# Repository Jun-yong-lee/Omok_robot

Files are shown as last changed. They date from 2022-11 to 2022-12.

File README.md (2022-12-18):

# Omok_robot
Omok robot(Senier Project)

omok_robot_play
## Link https://youtu.be/_ZdAu9by-7Q

## Matlab Simulation
<p align="center">

</p>

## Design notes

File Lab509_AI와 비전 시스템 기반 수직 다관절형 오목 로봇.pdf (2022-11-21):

# AI와 비전 시스템 기반 수직 다관절형 오목 로봇

## 이준용, 이성용, 박정섭, 김선혁(지도교수 김우용)

## 호서대학교 로봇공학과

## Department of Robotics, Hoseo University

- 사용자와 1대1 오목대국이 가능한 오목 로봇 제작
- 오목게임을 진행할 수 있는 대결 플랫폼 제작
- 오목판 격자무늬 포인트에 정확하게 돌을 착수 할 수 있는 제어 시스템 설계
- 오목판 모든 좌표에 돌을 둘 수 있는 5축 로봇팔 설계
✓ | DH 파라미터와 매트랩 시뮬레이션을 통한 로봇팔 길이 선정
✓ | 유성기어를 활용한 정밀성 및 토크 향상
- 다이나믹셀을 활용한 5축 로봇팔 제어
✓ | PID 제어기 설계를 통한 포지션 제어
✓ | 5축 로봇팔 제어를 통한 정확한 좌표로의 이동
- CV(Computer Vision)를 활용한 오목판 위의 돌의 좌표 추출
✓ | Sobel연산을 이용한 격자무늬 포인트 추출
✓ | Templete Matching을 이용한 오목돌 감지
- CNN(Convolution Neural)을 활용한 오목 AI 모델 생성

✓ FreeStyle Rule을 적용한 오목 AI 모델 생성

- Pygame을 활용한 UI(User Interface)제작
✓ 승패 판정 및 마우스 클릭 이벤트가 가능한 UI 제공

### 연구목표

서론

결론

<goboard detect> | <stone detect>

<detect result>

1. Soble연산을 이용한 오목판의 격자무늬 포인트 좌표 탐지
2. Templete Matching을 이용한 오목돌 좌표 탐지
3. 포인트와 오목돌 좌표를 비교 연산하여 실제 돌의 착수 좌표 검출
1. Gomocup Freestyle data 전처리를 통한 데이터 확보
2. CNN(Convolution Neural Network)을 활용한 오목 AI 모델 학습 진행
3. 실제 오목이 진행되는 배열을 입력으로 한 AI 모델 성능 검증

<CV detect result>

Hardware

1. 오목돌의 Pick & Place를 위해 5-axis Manipulator를 제작
2. 전체 내부의 구성은 모터와 모터 연결 축이 Manipulator 각 링크에 다이렉트로 연결
3. Joint 2번만 모터 토크 부족으로 Sun gear 기준 6:1 비율의 유성기어를 장착하여 토크 향상
4. Board Box, Dispenser와 함께 오목로봇 전체구성
<전체 Asembly> | <실제 외형>

Kinematics

1. Matlab을 이용하여 경기장에서 구동 가능한 수직 다관절형 로봇팔의 DH 파라미터를 선정
2. 그림1과 2는 오목판 좌표(4,4)의 역기구학 분석을 진행한 뒤, 그 결과를 순기구학을 이용하여 오목판, 로봇팔의 형태를 plot에 시각화
3. 그림 3은 제작된 로봇팔로 오목판의 모든 좌표에 오목돌 착수 가능여부를 시각화
<그림 1> | <그림 2> | <그림 3>

Firmware

1. 그림 4는 오목돌을 착수할 5축 로봇팔과 경기장의 자동화를 위한 오목돌 디스펜서의 전체적인 시스템 개략도
2. 그림 5는 오목 로봇을 구성하는데 사용된 DYNAMIXEL의 정보
3. 로봇팔의 돌 착수에는 다른 좌표에 두어진 오목돌을 피해 지나갈 수 있도록 End-Effector가 지정된 경로를 따라 진행하도록 경로설계를 진행
<그림 4> | <그림 5>

Computer Vision

CNN based AI

Pygame based UI

Omok Robot System

<AI model Layer Configuration>

<Accuracy Trend>

<Loss Trend>

- 오목로봇의 각각의 요소인 Hardware, Firmware, CV, AI, UI를 완성 & 연동
- 로봇과 사용자가 대결이 가능한 오목 로봇 플랫폼 완성
- AI가 융합된 교육 로봇 플랫폼 개발 가능성 제시
- 현재 개발된 모델과 매우 흡사한 바둑과 체스 등 다양한 시스템에 적용 가능
1. 사용자가 착수한 돌과 AI가 착수한 돌을 UI상에 출력
2. 턴이 끝나면 마다 오목 룰 알고리즘으로 게임 종료 판단
3. 사용자로부터 이름을 입력 받아 ranking system 구현

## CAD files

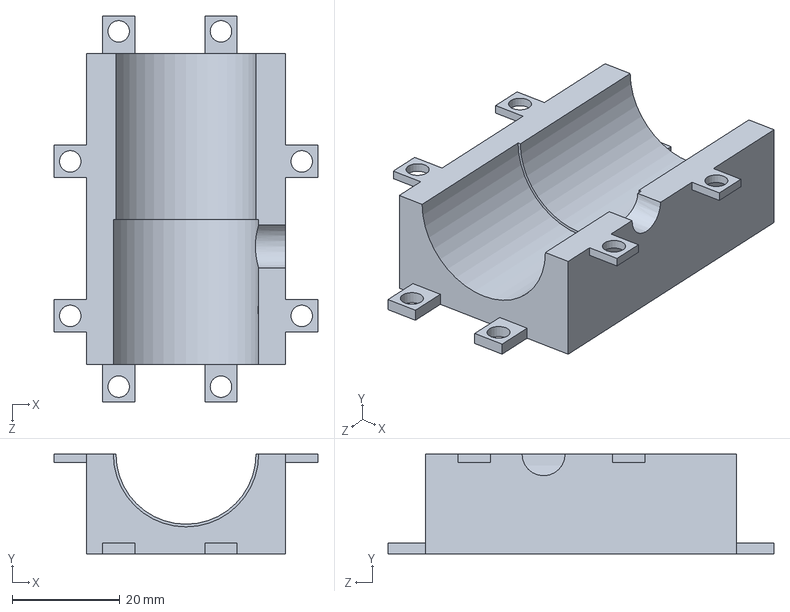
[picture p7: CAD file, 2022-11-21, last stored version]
design_board_box/Vacuum Pump case.SLDPRT
49.0 x 18.5 x 71.7 mm

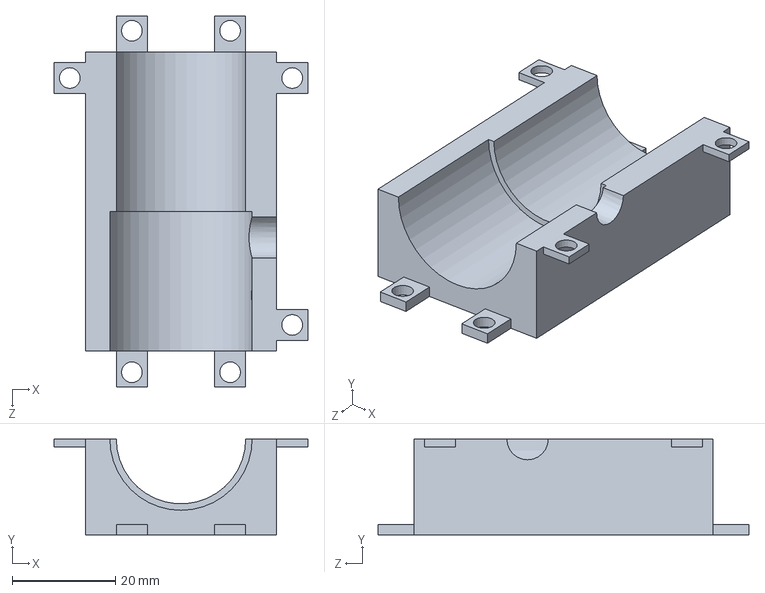
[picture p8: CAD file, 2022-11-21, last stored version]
design_board_box/치수 늘린 모터 케이스/치수_Vacuum Pump case 하.SLDPRT
49.0 x 18.5 x 71.7 mm

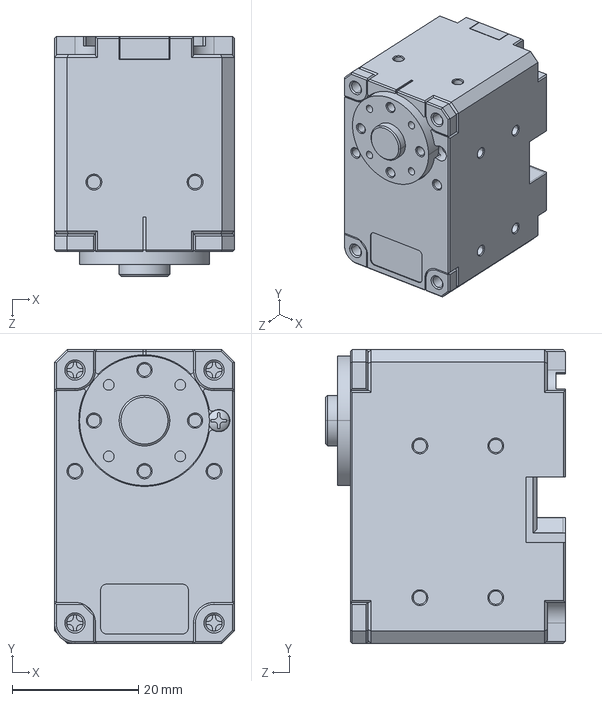
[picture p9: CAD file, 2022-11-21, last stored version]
design_dispenser/XL-430.SLDPRT
28.5 x 46.5 x 37.9 mm

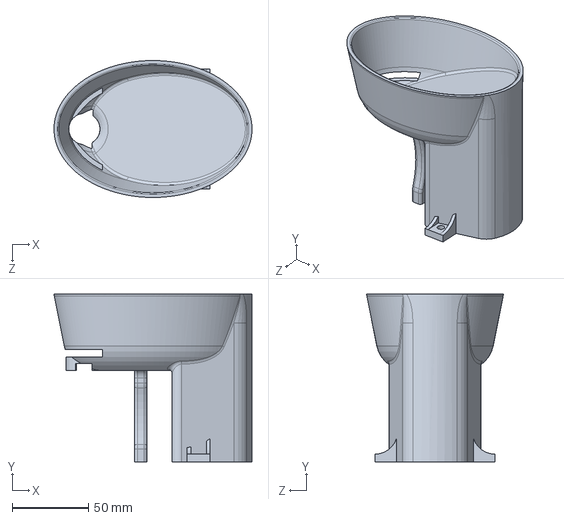
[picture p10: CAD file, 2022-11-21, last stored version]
design_dispenser/구조 변경/입X_stone case.SLDPRT
129.9 x 110.0 x 89.9 mm

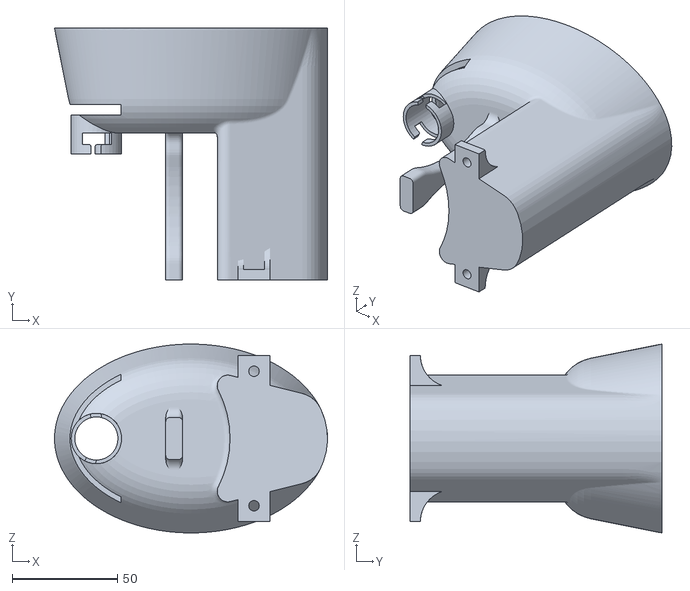
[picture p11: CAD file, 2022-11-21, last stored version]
design_dispenser/출력파일/stone case.STL
129.9 x 120.0 x 89.9

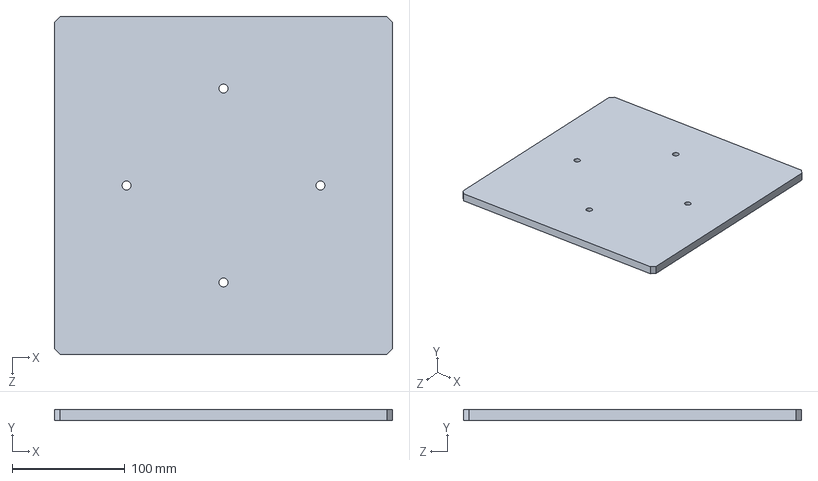
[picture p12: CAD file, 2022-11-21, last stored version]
design_place/Iron plate.SLDPRT
300.0 x 10.0 x 300.0 mm

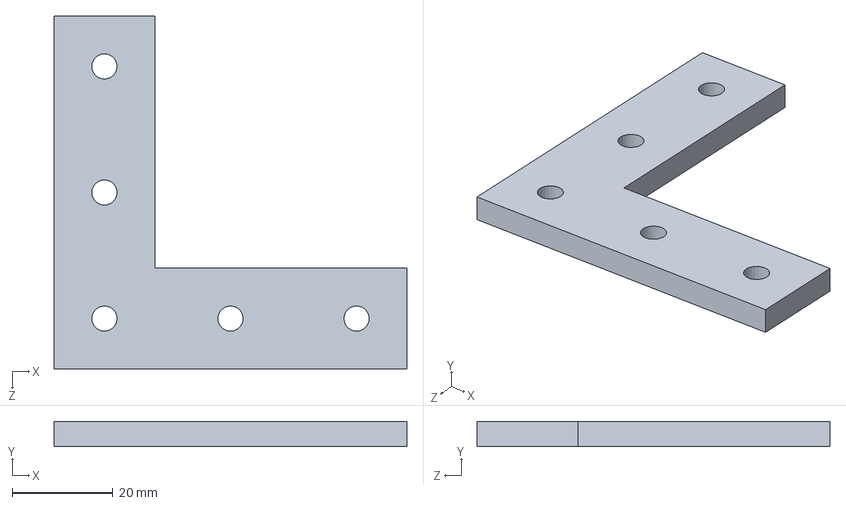
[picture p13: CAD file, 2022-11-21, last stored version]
ㄱ fixed flat.SLDPRT
70.0 x 5.00 x 70.0 mm

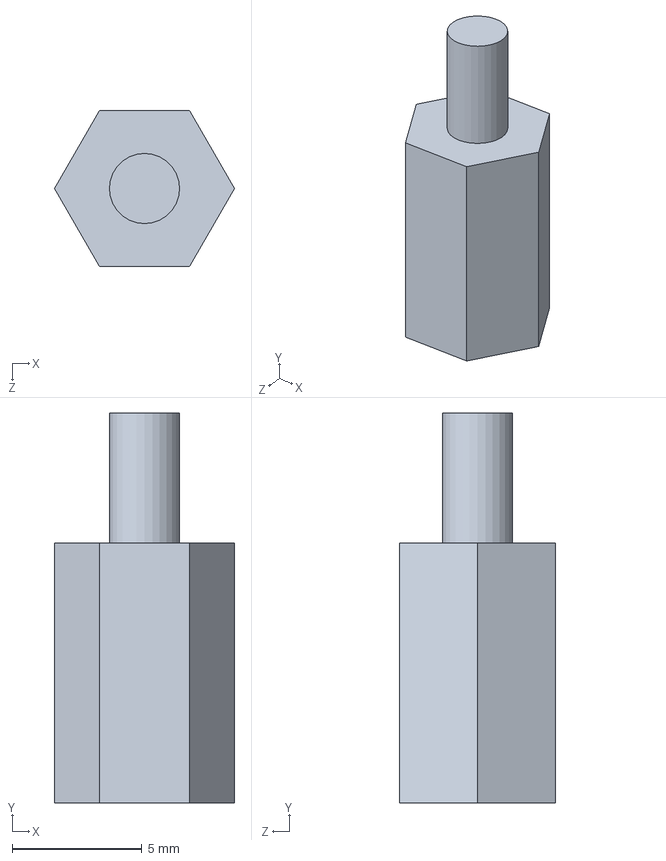
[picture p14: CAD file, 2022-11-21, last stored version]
design_board_box/board support_L10.SLDPRT
6.93 x 15.0 x 6.00 mm

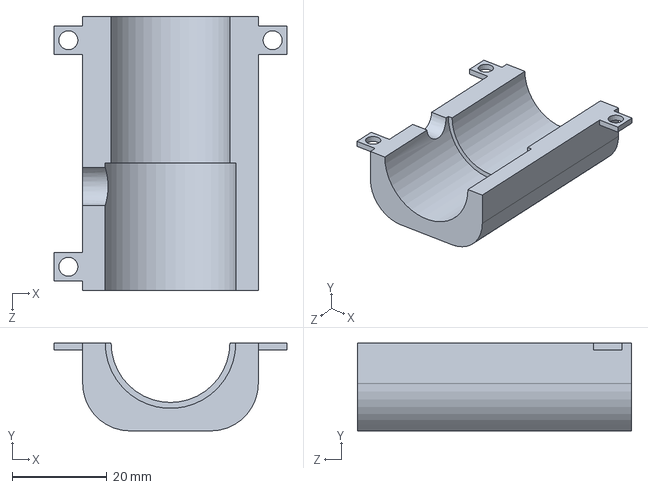
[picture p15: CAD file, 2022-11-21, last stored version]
design_board_box/치수 늘린 모터 케이스/치수_Vacuum Pump case 상.SLDPRT
49.0 x 18.5 x 57.7 mm

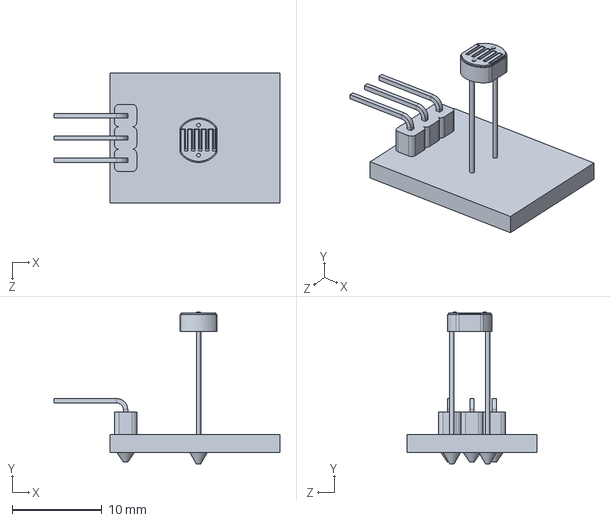
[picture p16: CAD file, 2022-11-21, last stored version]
design_dispenser/CDS module.SLDPRT
25.2 x 17.0 x 14.5 mm

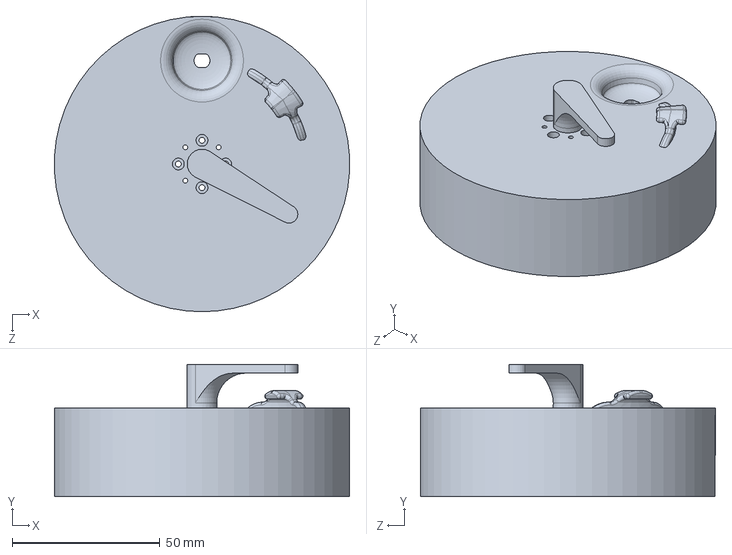
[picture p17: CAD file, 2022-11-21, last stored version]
design_dispenser/구조 변경/입X_Rotating plate.SLDPRT
99.9 x 44.8 x 100.0 mm

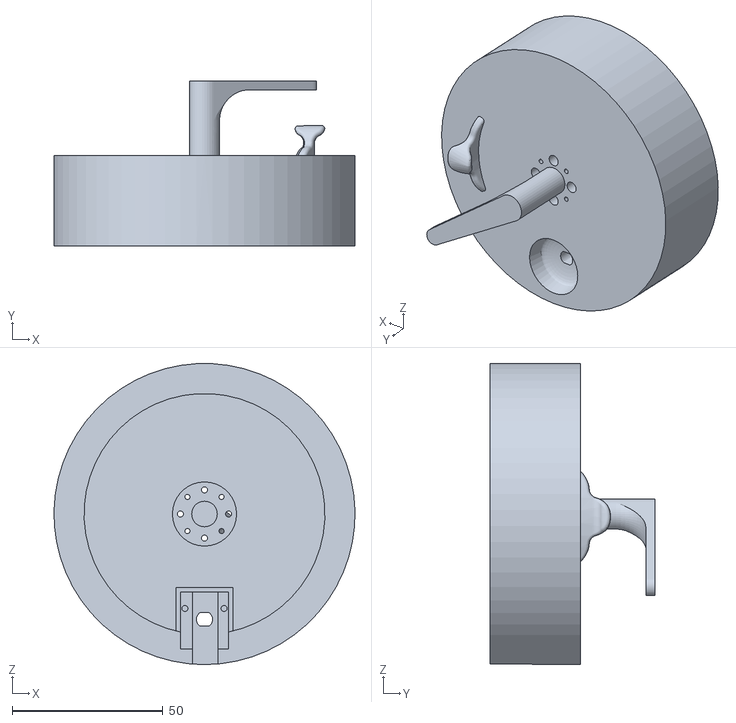
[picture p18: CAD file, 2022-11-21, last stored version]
design_dispenser/출력파일/Rotating plate.STL
100.0 x 54.8 x 100.0

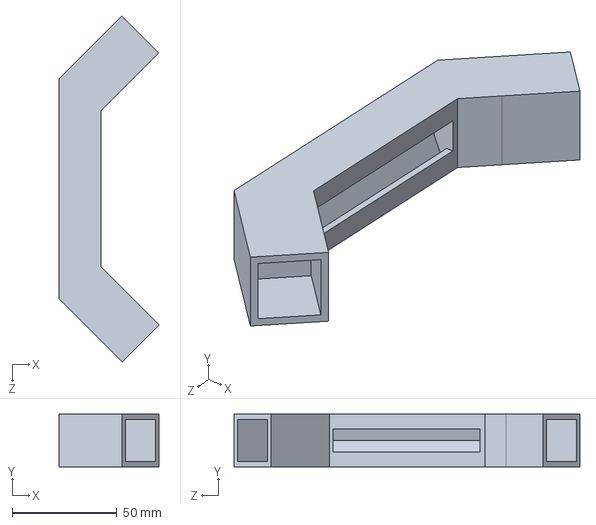
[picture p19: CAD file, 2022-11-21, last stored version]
design_place/Camera stand.SLDPRT
47.8 x 25.2 x 165.0 mm

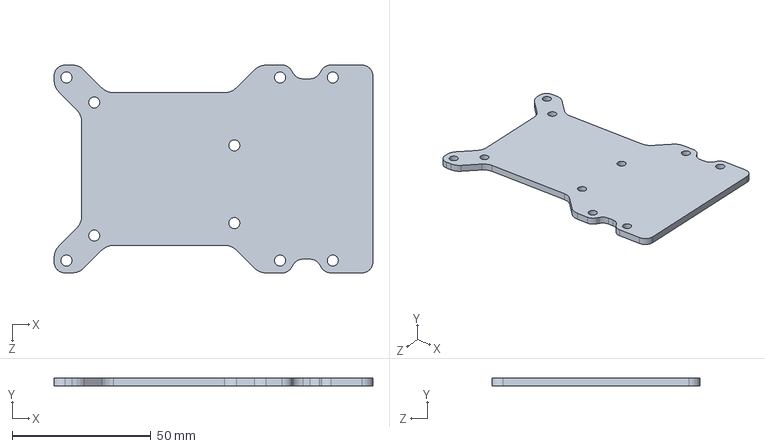
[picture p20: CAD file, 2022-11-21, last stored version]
design_board_box/2 plate.SLDPRT
115.0 x 3.00 x 75.0 mm

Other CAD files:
design_board_box/치수 늘린 모터 케이스/치수_solenoide fixed line.SLDPRT
design_dispenser/알.SLDPRT
design_place/Profile link.SLDPRT
design_board_box/solenoide fixed line.SLDPRT
design_board_box/1 plate.DWG
design_board_box/1 plate.SLDPRT
design_board_box/2 plate.DWG
design_board_box/Arduino uno.SLDPRT
design_board_box/SMD_R 1206 Body.stp.SLDPRT
design_board_box/SMD_R 1206 Connector.stp.SLDPRT
design_board_box/Sensor Board.SLDPRT
design_board_box/Vacuum Pump case 상.SLDPRT
design_board_box/Vacuum Pump case 상.STL
design_board_box/Vacuum Pump case.STL
design_board_box/Vacuum Pump.SLDPRT
design_board_box/board support_L20.SLDPRT
design_board_box/board support_L30.SLDPRT
design_board_box/board support_L5.SLDPRT
design_board_box/solenoide.SLDPRT
design_board_box/uno.step.SLDPRT
design_board_box/치수 늘린 모터 케이스/치수_Vacuum Pump case 상.STL
design_board_box/치수 늘린 모터 케이스/치수_Vacuum Pump case 하.STL
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

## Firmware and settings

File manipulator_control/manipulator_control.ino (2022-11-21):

/***********************************************************************************************************************
* Department of Robotics Hoseo University
* LAB509 Senier Project
* Project Name : Concave AI Manipulator System
* Project Period : 2022.01~2022.10
* < Lee Seong Yong > : Responsible for Making the Manipulator Controller
***********************************************************************************************************************/

/**********************************************************************************************************************
* Dynamixel : Extended Position Control Mode(OpenCR Board Use)
* 1) Joint1 : Dynamixel XH540-W270-T
* 2) Joint2 : Dynamixel XM540-W270-T
* 3) Joint3 : Dynamixel XM430-W350-T
* 4) End_Effector_A : Dynamixel 2XL430-W250-T(A)
* 5) End_Effector_B : Dynamixel 2XL430-W250-T(B)
***********************************************************************************************************************/
#include <Arduino.h>
#include <actuator.h>
#include <Dynamixel2Arduino.h>
#include <math.h>

HardwareTimer Timer(TIMER_CH1);

// Please modify it to suit your hardware.
#if defined(ARDUINO_AVR_UNO) || defined(ARDUINO_AVR_MEGA2560) // When using DynamixelShield
  #include <SoftwareSerial.h>
  SoftwareSerial soft_serial(7, 8); // DYNAMIXELShield UART RX/TX
  #define DXL_SERIAL   Serial
  #define DEBUG_SERIAL soft_serial
  const uint8_t DXL_DIR_PIN = 2; // DYNAMIXEL Shield DIR PIN
#elif defined(ARDUINO_SAM_DUE) // When using DynamixelShield
  #define DXL_SERIAL   Serial
  #define DEBUG_SERIAL SerialUSB
  const uint8_t DXL_DIR_PIN = 2; // DYNAMIXEL Shield DIR PIN
#elif defined(ARDUINO_SAM_ZERO) // When using DynamixelShield
  #define DXL_SERIAL   Serial1
  #define DEBUG_SERIAL SerialUSB
  const uint8_t DXL_DIR_PIN = 2; // DYNAMIXEL Shield DIR PIN
#elif defined(ARDUINO_OpenCM904) // When using official ROBOTIS board with DXL circuit.
  #define DXL_SERIAL   Serial3 //OpenCM9.04 EXP Board's DXL port Serial. (Serial1 for the DXL port on the OpenCM 9.04 board)
  #define DEBUG_SERIAL Serial
  const uint8_t DXL_DIR_PIN = 22; //OpenCM9.04 EXP Board's DIR PIN. (28 for the DXL port on the OpenCM 9.04 board)
#elif defined(ARDUINO_OpenCR) // When using official ROBOTIS board with DXL circuit.
  // For OpenCR, there is a DXL Power Enable pin, so you must initialize and control it.
  // Reference link : https://github.com/ROBOTIS-GIT/OpenCR/blob/master/arduino/opencr_arduino/opencr/libraries/DynamixelSDK/src/dynamixel_sdk/port_handler_arduino.cpp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
  #define DXL_SERIAL   Serial3
  #define DEBUG_SERIAL Serial
  const uint8_t DXL_DIR_PIN = 84; // OpenCR Board's DIR PIN.    
#else // Other boards when using DynamixelShield
  #define DXL_SERIAL   Serial1
  #define DEBUG_SERIAL Serial
  const uint8_t DXL_DIR_PIN = 2; // DYNAMIXEL Shield DIR PIN
#endif

// Dynamixel Motor BAUDRATE
#define BAUDRATE 57600

// Dynamixel XH540-W270-T : Joint(1)
#define J1_ID 1
// Dynamixel XM540-W270-T : Joint(2)
#define J2_ID 2
// Dynamixel XH540-W270-T : Joint(3)
#define J3_ID 3
// Dynamixel 2XL430-W250-T : End-Effector Ch(A)-Pitch Orientation, Ch(B)-Yaw Orientation
#define EA_ID 4
#define EB_ID 5

const uint8_t DXL_ID[5] = {J1_ID, J2_ID, J3_ID, EA_ID, EB_ID};
const float DXL_PROTOCOL_VERSION = 2.0;

Dynamixel2Arduino DXL(DXL_SERIAL, DXL_DIR_PIN);

// This namespace is required to use Control table item names
using namespace ControlTableItem;

// Dynamixel Postion Estimation Parameter
int Dynamixel_Position[5] = {0,0,0,0,0};
int Position_A[5] = {0,0,0,0,0};
float Position_B[5] = {0.0,0.0,0.0,0.0,0.0};
int Position_Function[5], Position_Sum = 0; // Position_Sum = All Dynamixel Position Error Sum
// Dynamixel Velocity
int Temp_V, Position_V[5], Encoder_E[5], Save_Encoder_E[5], Min_Encoder_E, Dynamixel_V[5];
/**********************************************************************************************************************
* 5DOFs Manipulator Angle Parameter
* radius : radius from Manipulator base to target point
* theta : Default Y Coordinate(theta = pi/2(radian) = 90(degree))
***********************************************************************************************************************/
double j_theta1, j_theta2, j_theta3, e_thetap;
const double e_thetay = 180.0;  //..Constant Yaw Orientation(not use 4DoFs)
double D_theta[5];              //.. = {j_theta1, j_theta2, j_theta3, e_thetap, e_thetay};
double radius, theta;           // radius, theta of coordinate(xv, yv)
/**********************************************************************************************************************
* 5DOFs Manipulator Reference Position Coordinate
***********************************************************************************************************************/
#define xrv 10
#define yrv 19
/**********************************************************************************************************************
* 5DOFs Manipulator Path Planning Parameter
***********************************************************************************************************************/
int N_resolution = 0;
int V_resolution = 0, S_resolution = 0;
double f_radius, f_theta;       // radius, theta of final coordinate(xrv, yrv)
double p_radius, p_theta;       // radius, theta of path planning coordinate
double r_radius, r_theta;       // radius, theta of reference coordinate(xrv, yrv)
/**********************************************************************************************************************
* 5DOFs Manipulator D-H Parameter
* L1,L2,L3 : Link Length[cm]
***********************************************************************************************************************/
double L1 = 23.43, L2 = 32.6, L3 = 28.9; // L1 = 24.13, L2 = 32.5, L3 = 23.8 (Link3 = 23.8 + 5)
double init_x = 0.0, init_y = 0.0;
double x, y, z, xd, yd, zd, rrx, rry, rrz;
double M_d, M_D, M_Ei;
double alpha, beta, r;
/**********************************************************************************************************************
* Square Plate Coordinate Data and 5DOFs Reference Axis Position Data
* base_radius : Manipulator Base Radius
* base_distance : Distance between Board and Manipulator start point
***********************************************************************************************************************/
double base_radius = 9.5, base_distance = 7.4, board_blank = 1.65; // base_distance = 7.4(standard) board_blank = 1.5 + 2.05[cm]
double origin = base_radius+base_distance+board_blank;
// ejector_height : 이젝터 높이, margin_height : 경로 이동을 위한 여유 높이, concave_position : Manipulator의 Base 위치로부터 오목돌의 기준 위치
// end-effector ejector height : 12.15cm
// 오목돌 높이 : 6.5~7.5mm : 0.65~0.75cm -> 평균 : 0.8cm, place_vertical_height : 오목돌 지정 좌표에서 수직 이동을 위한 변수
double stone_height = 0.75, place_vertical_height = 0, save_place_vertical_height = 0; // stone height : 0.7
double board_height = 1.3, board_square = 2.05, ejector_height = 12.15 + board_height + stone_height, vertical_height = ejector_height + 6, dispenser_height = ejector_height + 3, path_height = 0; // end-effector_ejector : 12.15, board_square : 2.05
// (X),(Y),(Z) Origin_Coordinate 대시 상태에서의 초기 기준 위치 선정(initial Position), init_case : Manipulator의 각도 보상기 적용 여부
// X_initial_Position = origin
double X_initial_Position = 10.7 + base_radius, Y_initial_Position = 0.0, Z_initial_Position = vertical_height, init_case = 0;
double X_stone_Position = 10.7 + base_radius, Y_stone_Position = 0.0, Z_stone_Position = vertical_height;

double J1_COMP[19][19] = {{0,0,0,0,0,0,0,0,0,0,0,0,0,0,0,0,0,0,0},
                          {0,0,0,0,0,0,0,0,0,0,0,0,0,0,0,0,0,0,0},
                          {-0.5,0,0,0,0,0,0,0,0,0,0,0,0,0,0,0,0,0,0},
                          {0,0,0,0,0,0,0,0,0,0,0,0,0,0,0,0,0,0,0},
                          {0,0,0,0,0,0,0,0,0,0,0,0,0,0,0,0,0,0,0},
                          {0,0,0,0,0,0,0,0,0,0,0,0,0,0.5,0,0,0,0,0},
                          {0,0,0,-0.2,0,0,0,0,0,0,0,0.5,0,0,0.5,0,0,0,0},
                          {0,-0.5,0,0,0,0,0,0,0,0,0,0,0,0.5,0,0,0,0.5,0},
                          {0,0,0,0,0,0,0,0,0,0,0,0,0,0,0.5,0.5,0,0,0.5},
                          {0,0,0,0,0,0,0,0,0,0,0,0.5,0.5,0.5,0,0.5,0,0,0.5},
                          {0,0,0,0,0,0,0,0.5,0,0,0.5,0,0,0,0.5,0.5,0.5,0,0},
                          {0,0,0,0,0,0,0.5,0,0,0,0,0,0.5,0,0.3,0.3,0,0.3,0.3},
                          {0,0,0,0.5,0,0,0,0.5,0,0,0,0,0.5,0,0.5,0,0,0,0.5},
                          {0,0,0,0,0,0,0,0,0,0,0,0,0,0,1,0,0.5,1,1},
                          {0,0,0,0,0,0,0,0.5,0,0,0,0.5,0,0,0,0,0,1,1},
                          {0,0,0,0,0.5,0,0,0,0,0,0,1,0,1,1,0.5,0,1,1},
                          {0,0,0.5,0.5,0,0,0,0,0,0,0,1,0,0,1,1,1,1,1},
                          {-0.5,0.5,0,0,-0.5,0.5,0.5,0.5,0.5,0,0,0.5,0.5,0.5,1,1,1,1,0.5},
                          {0,0,0,0.5,0.5,0,0,0.5,0,0,0,1,1,1,1,1,1,1,1}};


double J2_COMP[19][19] = {{0,0,0,0,0,0,0,0,0,0,0,0,0,0,0,0,0,0,0},
                          {0,0,0,0,0,0,0,0,0,0,0,0,0,0,0,0,0,0,0},
                          {0,0,0,0,0,0,0,0,0,0,0,0,0,0,0,0,0,0,0},
                          {0,0,0,0,0,0.4,0,0,0,0,0,0,0,0.4,0,0,0,0,0},
                          {0,0,0,0,0.2,0,0,0.2,0,0,0,0.4,0,0,0.4,0,0,0,0.4},
                          {0,0,0,0,0,0,0,0,0,0,0,0,0,0,0,0,0,0,0},
                          {0,0,0,0,0,0,0,0,0,0,0,0,0,0,0,0,0,0,0},
                          {0,0,0,0,0.2,0,0,0,0.2,0.2,0.2,0,0,0,0.2,0,0,0,0},
                          {0,0.2,0,0,0,0,0,0,0,0,0,0,0,0,0,0,0,0.2,0},
                          {0,0,0,0,0.2,0,0,0,0,0,0,0,0,0,-0.2,0,0,0,0},
                          {0,-0.2,0,0,0,0,-0.4,-0.2,0,0,0,0,0,0,0,0,0,0,0},
                          {0,-0.2,-0.2,-0.2,-0.2,-0.2,-0.2,-0.2,-0.2,0,-0.2,-0.2,0,0,0,0.2,0,-0.2,-0.2},
                          {0,0,0,0,0,0,0,0,0,0,0,0,0,0,0,-0.5,-0.2,0,-0.3},
                          {0,0,0,0,0,0,0,0,0,0,0,0,0,0,0,0,0,0,0},
                          {0,0,0,0,0,0,0,0,0,0,0,0,0,0,0,0,0.5,-0.2,0},
                          {0,0,0,0,0,0,0,0,0,0,0,0,0,0,0,0,0,0,0.2},
                          {0,0,0,0,0,0,0,0,0,0,0,0,0,0,0,0,0,0,0},
                          {0,0,0,0,0,0,0,0,0,0,0,0,0,0,0,0,0,0,0},
                          {0,0,0,0,0,0,0,0,0,0,0,0,0,0,0,0,0,0,0}};

double J3_COMP[19][19] = {{3,3,4,4,4,4,4.5,3,3,3,3,3,4,3.5,4,4,5,5,5},
                          {3,3,4,4,4,2,3,3,2,3,2,4,3,3,4,4,4,3,3},
                          {1.5,2.5,2.5,2.5,3,3,3.5,4.5,2.5,2.5,2.5,4,4,3,3,3,3,3,3},
                          {2.5,2.5,2.5,3.5,3,4.5,3,3,3.5,3.5,3.5,3.5,2.5,5,3.5,3.5,3.5,3,2.5},
                          {3.5,3.5,3.5,2.5,3.5,3,3.5,4.5,2,2,2,4.5,3.5,3.5,4.5,2.5,3.5,4.5,4},
                          {2,2.5,2,3,3,2.5,3.5,2,2.5,2.5,2.5,2.5,3.5,3,3,3,2,2.5,2.5},
                          {2,2.5,2.5,2.5,2.5,2.5,3.5,2,2,2,2,2,3.5,2.5,2.5,3,2.5,2.5,3},
                          {2,2,3,3,3.5,2.5,2.5,3,3.5,3.5,3.5,3.5,3.5,3,4,3.5,3.5,3,3},
                          {2,4,2,1.5,2.5,3.5,1.5,1.5,3,1.5,1.5,2,2,3.5,3,1.5,2,3.5,2.5},
                          {3,2.5,1.5,1.5,3,1.5,2,3.5,3.5,1,3.5,3,2.5,1.5,1.5,2,1.5,2,4},
                          {1.5,0,1.5,4,1,2,1,1,1.5,0.5,1.5,3.5,3,2,2,3.5,2,3.5,2.5},
                          {1.5,1.5,1,1,1,1.5,1.5,1.5,1,1,1,1,2.5,1.5,1.5,2.5,1.5,1.5,1.5},
                          {1,0,1,0,1,0.5,1,1,1,1,1.5,1.5,1.5,1.5,1.5,1.5,1,1,1.5},
                          {0,0.5,0,0,0.5,1,0,0,0,0.5,0,0,0,0.5,0.5,0,0,1,1},
                          {0,0,0.5,0,0.5,0,0,0,0,0.5,0,0,0,0,0.5,0,1,2,0.5},
                          {0.5,0,0.5,0.2,0.5,0,0,0,0,0,0,0,0,0,0.5,0,0,0.5,2},
                          {0,0,0,0,0,0,0,0,0,0,0,0,0,0.5,0,0.5,0,0,0.5},
                          {0,0,0,0,0,0.5,0,0,0,-0.2,0,0,0,1,0,0,0,0,0},
                          {0.5,0,0,0,0,0,0,0,0,0,0,0,0,0,0,0,0,0,0.5}};
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
void loop() // put your main code here, to run repeatedly:
{
  Dispenser_CDS_Sensing_DXL_Drive_Function();
  Checkerboard_Coordinate_Data();
  if(xv != 0 && yv != 0)
  {
    /*
    init_case = 0; // 각도 보상기 X
    init_case = 1; // 각도 보상기 O
    */
    /***********************************************************
    * Manipulator Drive Mode Sequence
    * 1) 좌표 데이터 받기 전 or 로봇팔 작동 전 : 오목돌 디스펜서(OMOK STONE DISPENSER) 항시 작동
    * 2) 좌표계 이동을 위한 DYNAMIXEL 각도 정보 추출 및 저장
    * 3) MANIPULATOR END-EFFECTOR EJECTOR로 오목돌 흡입 위치로 이동 및 집기
    * 4) STANDBY 위치로 복귀하여 REFERENCE 위치(xrv = 10, yrv = 19)로 이동
    * 5) MANIPULATOR FINAL 위치로 PATH PLANNING(PATH CASE = 0) FORWARD MODE로 이동
    * 6) MANIPULATOR FINAL 위치에서 오목돌 놓을 수 있는 EJCETOR POSITION(ej_po)로 이동하여 오목돌 착수
    * 7) MANIPULATOR FINAL 위치를 유지하며 PATH PLAN POSITION인 높이 VERTICAL POSITION(vt_po)로 이동
    * 8) MANIPULATOR REFERENCE 위치로 PATH PLANNING(PATH CASE = 1) INVERSE MODE로 이동
    * 9) STANDBY 위치로 복귀(x_standby_init, y_standby_init, z_standby_init)
    ***********************************************************/
    Save_Position_Calculation(xv,yv);   // Path Planning 데이터 추출하기 위함(이 데이터를 for문 활용하여 구현할 것)
    Data_Verification();                // 시리얼 모니터 데이터 확인용
    init_case = 0;
    for(int n = 0;n < S_resolution;n++)
    {
      place_vertical_height = (double)fabs(vertical_height - dispenser_height)/S_resolution;
      Manipulator_Stone_Position(X_stone_Position, Y_stone_Position, vertical_height - ((n + 1)*place_vertical_height));
      if(n == S_resolution - 1) save_place_vertical_height = vertical_height - ((n + 1)*place_vertical_height);
    }
    Waiting(S_resolution*100);
    Ejector_Logic(Ejector_A_PIN, Ejector_B_PIN);                                          // 오목돌 흡입
    for(int n = 0;n < S_resolution;n++)
    {
      place_vertical_height = (double)fabs(vertical_height - dispenser_height)/S_resolution;
      Manipulator_Stone_Position(X_stone_Position, Y_stone_Position, save_place_vertical_height + ((n + 1)*place_vertical_height));
    }
    Waiting(S_resolution*50);
    cdsv_loop = analogRead(CDS);
    while(cdsv_loop > 1000)
    {
      cdsv_loop = 0;
      for(int n = 0;n < S_resolution;n++)
      {
        place_vertical_height = (double)fabs(vertical_height - dispenser_height)/S_resolution;
        Manipulator_Stone_Position(X_stone_Position, Y_stone_Position, vertical_height - ((n + 1)*place_vertical_height));
        if(n == S_resolution - 1) save_place_vertical_height = vertical_height - ((n + 1)*place_vertical_height);
      }
      Waiting(S_resolution*100);
      Ejector_Logic(Ejector_A_PIN, Ejector_B_PIN);                                          // 오목돌 흡입
      for(int n = 0;n < S_resolution;n++)
      {
        place_vertical_height = (double)fabs(vertical_height - dispenser_height)/S_resolution;
        Manipulator_Stone_Position(X_stone_Position, Y_stone_Position, save_place_vertical_height + ((n + 1)*place_vertical_height));
      }
      Waiting(S_resolution*50);
      cdsv_loop = analogRead(CDS);
    }
    Manipulator_Drive_Reference_Position(xrv, yrv, vertical_height, 25);
    Waiting(2500);
    /*********************************************************** 
    * Path Planning Go Goal Position
    ***********************************************************/
    init_case = 1;
    for(int n = 0;n < N_resolution;n++)
    {
      if(xv == 10 && yv == 19) break;
      radius += p_radius;
      theta += p_theta;
      if(n < (N_resolution/2)) vertical_height += path_height/(N_resolution/2);
      else vertical_height -= path_height/(N_resolution/2);
      Manipulator_Path_Drive_Position(radius, theta, vertical_height);
    }
    Waiting(N_resolution*50);
    for(int n = 0;n < V_resolution;n++)
    {
      place_vertical_height = (double)fabs(vertical_height - (ejector_height + H_COMP[yv-1][xv-1]))/V_resolution;
      Manipulator_Path_Drive_Position(radius, theta, vertical_height - ((n + 1)*place_vertical_height));
      if(n == V_resolution - 1) save_place_vertical_height = vertical_height - ((n + 1)*place_vertical_height);
    }
    Waiting(V_resolution*100);
    for(int n = 0;n < V_resolution;n++)
    {
      if(n < 2) Ejector_Logic(Ejector_B_PIN, Ejector_A_PIN);
      place_vertical_height = (double)fabs(vertical_height - (ejector_height + H_COMP[yv-1][xv-1]))/V_resolution;
      Manipulator_Path_Drive_Position(radius, theta, save_place_vertical_height + ((n + 1)*place_vertical_height));
    }
    /*********************************************************** 
    * Path Planning Back Reference Position
    ***********************************************************/
    for(int n = 0;n < N_resolution;n++)
    {
      if(xv == 10 && yv == 19) break;
      radius -= p_radius;
      theta -= p_theta;
      if(n < (N_resolution/2)) vertical_height += path_height/(N_resolution/2);
      else vertical_height -= path_height/(N_resolution/2);
      Manipulator_Path_Drive_Position(radius, theta, vertical_height);
    }
    Waiting(N_resolution*50);
    init_case = 0;
    Manipulator_initial_Position(X_initial_Position, Y_initial_Position, Z_initial_Position, 20);
    xv = yv = 0;
    
    // 다이나믹셀 속도 데이터 확인용
    for(int i = 0;i < 5;i++)
    {
      DEBUG_SERIAL.print((String)Dynamixel_V[i] + "\t");
    }
    DEBUG_SERIAL.println("");
  }
}

void Save_Position_Calculation(double xfv, double yfv) // final coordinate (x,y) input = (xv,yv)
{
  Coordinate_Position_Calculation(xfv, yfv, vertical_height);
  f_radius = radius;f_theta = theta;
  Coordinate_Position_Calculation(xrv, yrv, vertical_height);
  r_radius = radius;r_theta = theta;
  N_resolution = (int)abs(2*sqrt(sq(10-xfv)+sq(19-yfv))); // 2*(X)
  path_height = N_resolution*0.075; // 0.125
  Manipulator_5DoFs_Path_Planning_Calculation(xfv, N_resolution);
  S_resolution = 8;
  V_resolution = 10;// (int)2 + sqrt(yfv);
  //if(yv < 4) V_resolution = 15;
}

void Data_Verification()
{
  DEBUG_SERIAL.println((String) "...\nInput Concave Coordinate(X,Y) : (" + xv + "," + yv + ")");
  DEBUG_SERIAL.println((String) ">> Joint(1) : " + j_theta1);
  DEBUG_SERIAL.println((String) ">> Joint(2) : " + j_theta2);
  DEBUG_SERIAL.println((String) ">> Joint(3) : " + j_theta3);
  DEBUG_SERIAL.println((String) ">>    Pitch : " + e_thetap);
  DEBUG_SERIAL.println((String) ">>      Yaw : " + e_thetay);
  DEBUG_SERIAL.println((String) "N_resolution: " + N_resolution);
  DEBUG_SERIAL.println((String) "Path Height : " + path_height);
}

void Manipulator_initial_Position(double xi, double yi, double zi, int dvr)
{
  radius = sqrt(sq(xi)+sq(yi));
  theta = PI;
  xd = init_x+(radius*cos(theta));
  yd = init_y+(radius*sin(theta));
  zd = zi;
  Manipulator_5DoFs_Rotation_Orientation_Calculation();
  Dynamixel_Position_Detail_Drive(dvr); // Dynamixel_Position_Estimation_Drive(dvr);
}

void Manipulator_Stone_Position(double xi, double yi, double zi)
{
  radius = sqrt(sq(xi)+sq(yi));
  theta = PI;
  xd = init_x+(radius*cos(theta));
  yd = init_y+(radius*sin(theta));
  zd = zi;
  Manipulator_5DoFs_Rotation_Orientation_Calculation();
  Dynamixel_Position_Estimation_Drive();
}

void Manipulator_Drive_Position(double xm, double ym, double zm)
{
  Coordinate_Position_Calculation(xm, ym, zm);
  Manipulator_5DoFs_Rotation_Orientation_Calculation();
  Dynamixel_Position_Estimation_Drive();
}
/*********************************************************** 
* Reference Position (x,y) : (10,19) Position Control
***********************************************************/
void Manipulator_Drive_Reference_Position(double xm, double ym, double zm, int dvr)
{
  Coordinate_Position_Calculation(xm, ym, zm);
  Manipulator_5DoFs_Rotation_Orientation_Calculation();
  Dynamixel_Position_Detail_Drive(dvr);
}

/*********************************************************** 
* Path Planning Position Control
***********************************************************/
void Manipulator_Path_Drive_Position(double xp, double yp, double zp)
{
  Path_Position_Calculation(xp, yp, zp);
  Manipulator_5DoFs_Rotation_Orientation_Calculation();
  Dynamixel_Position_Estimation_Drive();
}

void Waiting(int st)
{
  delay(st);
}

/*****************************************************************************************************************
* Vacuum Ejector Drive Signal Transfer Function
******************************************************************************************************************/
void Ejector_init()
{
  pinMode(Ejector_A_PIN, OUTPUT);
  pinMode(Ejector_B_PIN, OUTPUT);
  digitalWrite(Ejector_A_PIN, LOW);
  digitalWrite(Ejector_B_PIN, LOW);
}

void Ejector_Logic(int Ejector_HIGH_PIN, int Ejector_LOW_PIN)
{
  digitalWrite(Ejector_HIGH_PIN, HIGH);
  digitalWrite(Ejector_LOW_PIN, LOW);
  delay(500);
  digitalWrite(Ejector_HIGH_PIN, LOW);
  digitalWrite(Ejector_LOW_PIN, LOW);
}
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

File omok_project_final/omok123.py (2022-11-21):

import numpy as np
from tensorflow.keras.models import load_model
import cv2
from goboard_edge_detect import goboard_edge_detect_module, centroids_sort, index_to_coordinate, data_stone_package
from gostone_matching import gostone_matching_module, stone_55_list
import pygame, sys
from pygame.locals import *
from gomoku import Board, Gomoku
from rule import *
import threading
from multiprocessing import Process
import multiprocessing as mp

w, h = 20, 20
board_1 = Board(w=w, h=h)
game = Gomoku(board=board_1)
model = load_model('20210307_232530.h5')

check_num = 0
global now_black_stone
global centroids, flag, img_board, check_stone, black_stone_n, white_stone_n
bg_color = (128, 128, 128)
black = (0, 0, 0)
blue = (0, 50, 255)
white = (255, 255, 255)
red = (255, 0, 0)
green = (0, 200, 0)

window_width = 1280
window_height = 800
board_width = 800
grid_size = 40

fps = 60
fps_clock = pygame.time.Clock()


class Omok(object):
    def __init__(self, surface):
        self.board = [[0 for i in range(board_size)] for j in range(board_size)]
        self.menu = Menu(surface)
        self.rule = Rule(self.board)
        self.surface = surface
        self.pixel_coords = []
        self.set_coords()
        self.set_image_font()
        self.is_show = True

    def init_game(self):
        self.turn = black_stone
        self.draw_board()
        self.menu.show_msg(empty)
        self.init_board()
        self.coords = []
        self.redos = []
        self.id = 1
        self.is_gameover = False
        self.is_forbidden = False

    def set_image_font(self):
        black_img = pygame.image.load('image/black.png')
        white_img = pygame.image.load('image/white.png')
        self.last_w_img = pygame.image.load('image/white_a.png')
        self.last_b_img = pygame.image.load('image/black_a.png')
        self.board_img = pygame.image.load('omokBoard.png')
        self.forbidden_img = pygame.image.load('image/forbidden.png')
        self.font = pygame.font.Font("freesansbold.ttf", 14)
        self.black_img = pygame.transform.scale(black_img, (grid_size, grid_size))
        self.white_img = pygame.transform.scale(white_img, (grid_size, grid_size))

    def init_board(self):
        for y in range(board_size):
            for x in range(board_size):
                self.board[y][x] = 0

    def draw_board(self):
        self.surface.blit(self.board_img, (0, 0))

    def draw_image(self, img_index, x, y):
        img = [self.black_img, self.white_img, self.last_b_img, self.last_w_img, self.forbidden_img]
        self.surface.blit(img[img_index], (x + 20, y + 20))

    def show_number(self, x, y, stone, number):
        colors = [white, black, red, red]
        color = colors[stone]
        self.menu.make_text(self.font, str(number), color, None, y + 40, x + 40, 1)

    def hide_numbers(self):
        for i in range(len(self.coords)):
            x, y = self.coords[i]
            self.draw_image(i % 2, x, y)
        if self.coords:
            x, y = self.coords[-1]
            self.draw_image(i % 2 + 2, x, y)

    def show_numbers(self):
        for i in range(len(self.coords)):
            x, y = self.coords[i]
            self.show_number(x, y, i % 2, i + 1)
        if self.coords:
            x, y = self.coords[-1]
            self.draw_image(i % 2, x, y)
            self.show_number(x, y, i % 2 + 2, i + 1)

    def check_forbidden(self):
        if self.turn == black_stone:
            coords = self.rule.get_forbidden_points(self.turn)
            while coords:
                x, y = coords.pop()
                x, y = x * grid_size + 20, y * grid_size + 20
                self.draw_image(4, x, y)
            self.is_forbidden = True

    def draw_stone(self, coord, stone, increase):
        if self.is_forbidden:
            self.draw_board()
        x, y = self.get_point(coord)
        self.board[y][x] = stone
        self.hide_numbers()
        if self.is_show:
            self.show_numbers()
        self.id += increase
        self.turn = 3 - self.turn
        self.check_forbidden()

    def undo(self):
        if not self.coords:
            return
        self.draw_board()
        coord = self.coords.pop()
        self.redos.append(coord)
        self.draw_stone(coord, empty, -1)

    def undo_all(self):
        if not self.coords:
            return
        self.id = 1
        self.turn = black_stone
        while self.coords:
            coord = self.coords.pop()
            self.redos.append(coord)
        self.init_board()
        self.draw_board()

    def redo(self):
        if not self.redos:
            return
        coord = self.redos.pop()
        self.coords.append(coord)
        self.draw_stone(coord, self.turn, 1)

    def set_coords(self):
        for y in range(board_size):
            for x in range(board_size):
                self.pixel_coords.append((x * grid_size, y * grid_size))

    def get_coord(self, pos):
        for coord in self.pixel_coords:
            x, y = coord
            rect = pygame.Rect(x, y, grid_size, grid_size)
            if rect.collidepoint(pos):
                return coord
        return None

    def get_point(self, coord):
        x, y = coord
        x = (x) // grid_size
        y = (y) // grid_size
        return x, y

    def check_board(self, pos):
        coord = self.get_coord(pos)
        if not coord:
            return False
        x, y = self.get_point(coord)
        if self.board[y][x] != empty:
            print("occupied")
            return True

        if self.turn == black_stone:
            if self.rule.forbidden_point(x, y, self.turn):
                print("forbidden point")
                return True

        self.coords.append(coord)
        self.draw_stone(coord, self.turn, 1)
        if self.check_gameover(coord, 3 - self.turn):
            self.is_gameover = True
        if len(self.redos):
            self.redos = []
        return True

    def check_gameover(self, coord, stone):
        x, y = self.get_point(coord)
        if self.id > board_size * board_size:
            self.show_winner_msg(stone)
            return True
        elif self.rule.is_gameover(x, y, stone):
            self.show_winner_msg(stone)
            return True
        return False

    def show_winner_msg(self, stone):
        for i in range(3):
            self.menu.show_msg(stone)
            pygame.display.update()
            pygame.time.delay(200)
            self.menu.show_msg(empty)
            pygame.display.update()
            pygame.time.delay(200)
        self.menu.show_msg(stone)
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

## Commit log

2022-11-21 Add files via upload
    manipulator arduino control code
2022-11-21 Add files via upload
    Lab509_AI와 비전 시스템 기반 수직 다관절형 오목 로봇
2022-11-21 Add files via upload
    final omok robot
    [ranking.xlsx, ranking1.xlsx, ranking_copy.xlsx]
2022-11-21 Add files via upload
    board_box design_file
    [1 plate.DWG, 1 plate.SLDPRT, 2 plate.DWG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]
2022-11-21 Add files via upload
    dispenser desing_file
    [CDS module.SLDPRT, Motor fixed flat.SLDPRT, Rotating plate.SLDPRT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]
2022-11-21 Add files via upload
    place design_place
    [Camera stand.SLDPRT, Cart.SLDPRT, Checkerboard.SLDPRT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]
